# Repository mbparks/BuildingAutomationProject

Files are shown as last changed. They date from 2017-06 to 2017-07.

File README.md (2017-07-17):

# Building Automation Project
brought to you by Mouser Electronics

This repo holds all the information needed to experiment with an IoT-based building automation system that leverages the TE Connectivty Weather Shield.

Current Architecture:
- Arduino 101, 8266 WiFi Shield, TE Connectivity Weather Shield: Sensor package monitors temperature, pressure, and relative humidity. Transmits data to a cloud-based backend.
- Huzzah 8266 monitors data from cloud and makers decision to control ventilation dampers based on presets and current sensor reading.
- Leverage the Ubidots cloud service for the backend.  https://ubidots.com

Bill of Materials (BOM) in a pre-built shopping cart for your convenience:
http://www.mouser.com/ProjectManager/ProjectDetail.aspx?AccessID=098ee3c674

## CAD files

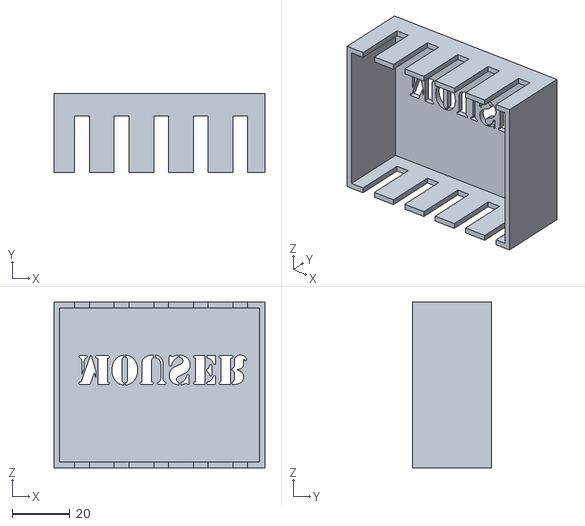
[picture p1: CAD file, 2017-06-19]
Mechanical/Arduino101Components/Arduino101EnclosureTop.stl
73.4 x 27.4 x 57.7

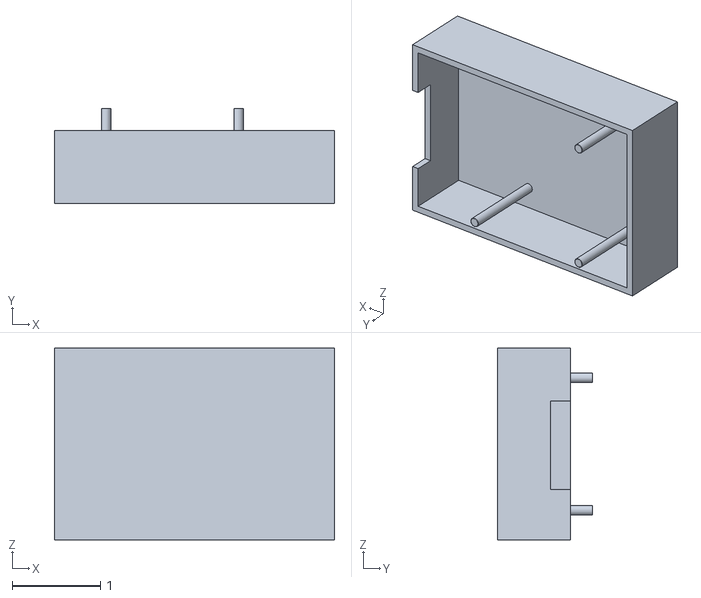
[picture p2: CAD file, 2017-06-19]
Mechanical/HuzzahComponents/HuzzahEnclosureBottom.stl
3.17 x 1.08 x 2.17

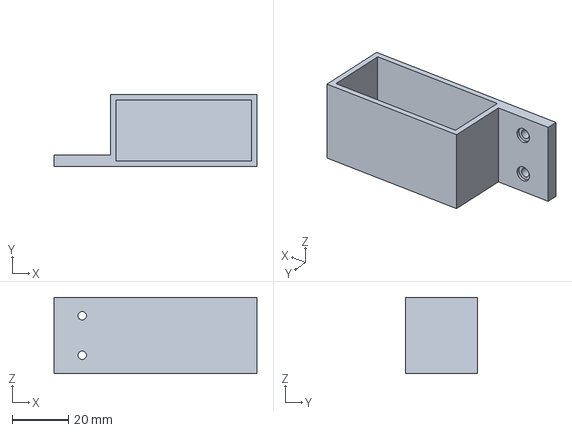
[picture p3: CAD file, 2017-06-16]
Mechanical/ServoMount/ServoHolder (1).amf
72.0 x 25.5 x 27.0 mm

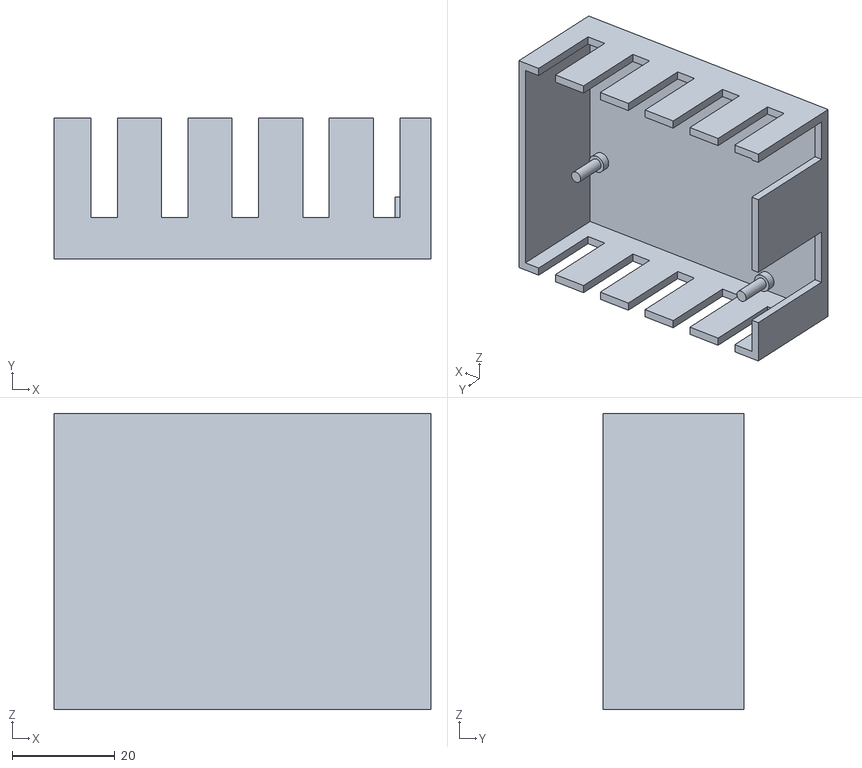
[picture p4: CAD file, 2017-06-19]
Mechanical/Arduino101Components/Arduino101EnclosureBottom.stl
73.4 x 27.4 x 57.7

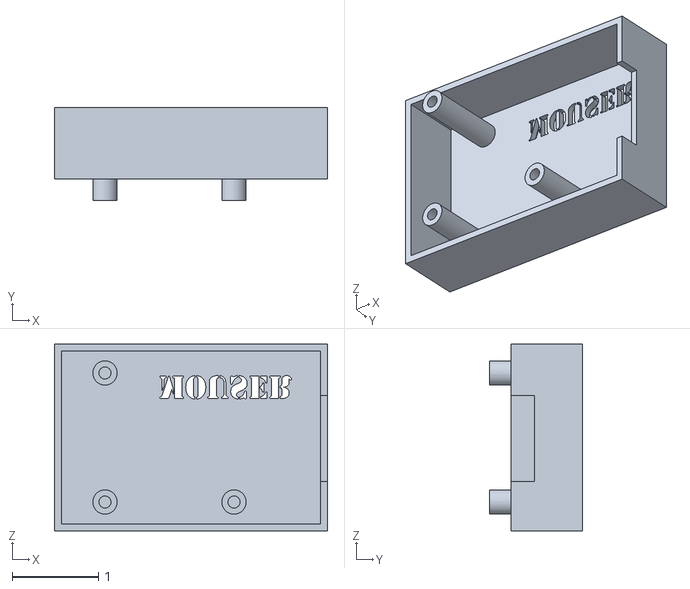
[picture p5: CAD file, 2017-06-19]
Mechanical/HuzzahComponents/HuzzahEnclosureTop.stl
3.17 x 1.08 x 2.17

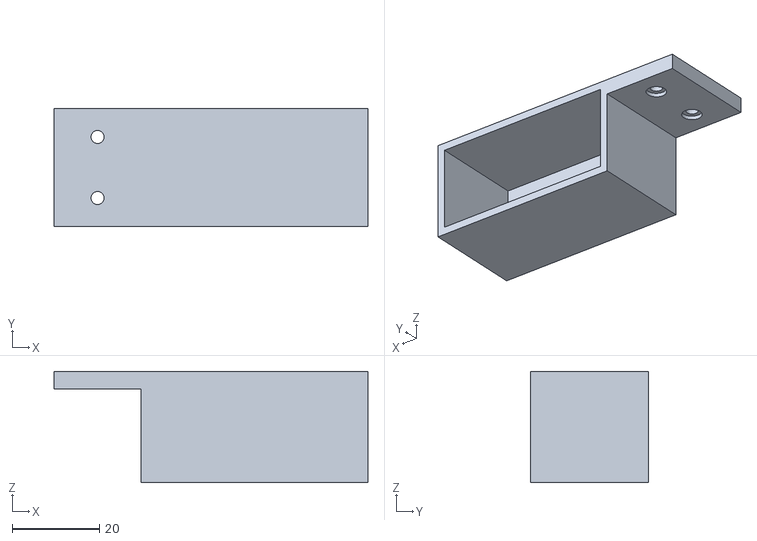
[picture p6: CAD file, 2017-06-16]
Mechanical/ServoMount/ServoHolder.stl
72.0 x 27.0 x 25.5

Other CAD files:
Mechanical/HuzzahComponents/HuzzahEnclosure.f3d
Mechanical/ServoMount/ServoHolder.f3d

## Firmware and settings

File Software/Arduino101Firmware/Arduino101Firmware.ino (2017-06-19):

////////////////////////////////////////
//
////////////////////////////////////////
#include <TEWeatherShield.h>
#include <SoftwareSerial.h> 
#include <SparkFunESP8266WiFi.h>

static TEWeatherShield  weatherShield;

const char mySSID[] = "";
const char myPASS[] = "";

const char ubidotsToken[] = "";
const char humidVarId[] = "";
const char tempVarId[] = "";
const char pressVarId[] = "";
const char destServer[] = "things.ubidots.com";

const int loopDelay = 30000;



/////////////////////////////////////////
//
////////////////////////////////////////
void setup() {
    Serial.begin(9600);
    delay(1000);
    
    // initializeESP8266() verifies communication with the WiFi
    // shield, and sets it up.
    initializeESP8266();

    // connectESP8266() connects to the defined WiFi network.
    connectESP8266();

    // displayConnectInfo prints the Shield's local IP
    // and the network it's connected to.
    displayConnectInfo();
    
    delay(2000);
    weatherShield.begin();
    delay(2000);
    
    Serial.println(F("Mouser Building Automation System Initialized."));
}



/////////////////////////////////////////
//
////////////////////////////////////////
void loop() {
    ESP8266Client client;
    float temperature = -1, pressure = -1, humidity = -1;
    getMeasurements(&temperature, &pressure, &humidity);
    temperature = (temperature * 1.8) + 32;

    int sizeOfPacket = 159;
    sizeOfPacket += getSize(temperature);
    sizeOfPacket += getSize(pressure);
    sizeOfPacket += getSize(humidity);
  

    if(client.connect(destServer, 80)) {
      Serial.println("Connected to Ubidots server, sending payload..");
      
      client.print("POST /api/v1.6/collections/values/?token=");
      client.print(ubidotsToken);
      client.println(" HTTP/1.1");
      client.println("Host: things.ubidots.com");
      client.println("Content-Type: application/json");
      client.print("Content-Length: ");
      client.println(sizeOfPacket);
      client.println();
      client.print("[{\"variable\": \"");
      client.print(tempVarId);
      client.print("\", \"value\":");
      client.print(temperature);
      client.print("}, {\"variable\": \"");
      client.print(humidVarId);
      client.print("\", \"value\":");
      client.print(humidity);
      client.print("}, {\"variable\": \"");
      client.print(pressVarId);
      client.print("\", \"value\":");
      client.print(pressure);
      client.println("}]");

      Serial.print(F("POST /api/v1.6/collections/values/?token="));
      Serial.print(ubidotsToken);
      Serial.println(F(" HTTP/1.1"));
      Serial.println(F("Host: things.ubidots.com"));
      Serial.println(F("Content-Type: application/json"));
      Serial.print(F("Content-Length: "));
      Serial.println(sizeOfPacket);
      Serial.println();
      Serial.print("[{\"variable\": \"");
      Serial.print(tempVarId);
      Serial.print(F("\", \"value\":"));
      Serial.print(temperature);
      Serial.print(F("}, {\"variable\": \""));
      Serial.print(humidVarId);
      Serial.print(F("\", \"value\":"));
      Serial.print(humidity);
      Serial.print(F("}, {\"variable\": \""));
      Serial.print(pressVarId);
      Serial.print(F("\", \"value\":"));
      Serial.print(pressure);
      Serial.println(F("}]"));

      }
      else {
        Serial.println("Cannot conenct ot to Ubidots server!!!");
      }
      
  // available() will return the number of characters
  // currently in the receive buffer.
  while (client.available()) {
    Serial.write(client.read());
  }// read() gets the FIFO char
  
  // connected() is a boolean return value - 1 if the 
  // connection is active, 0 if it's closed.
  if (client.connected()) {
    client.stop(); // stop() closes a TCP connection.
  }

  delay(loopDelay);
}


/////////////////////////////////////////
//
////////////////////////////////////////
void getMeasurements(float *t, float *p, float *h) {
  weatherShield.selectMS8607();

  while(!weatherShield.MS8607.is_connected()) {
    //wait
  }

  if (weatherShield.MS8607.is_connected()) {    
    weatherShield.MS8607.set_humidity_i2c_master_mode(ms8607_i2c_hold); 
    weatherShield.MS8607.read_temperature_pressure_humidity(t, p, h);
    Serial.println();
    Serial.print(F("Temperature : "));
    Serial.print(*t);
    Serial.println(F("C"));

    Serial.print(F("- Pressure : "));
    Serial.print(*p);
    Serial.println(F(" hPa"));
    
    Serial.print(F("- Humidity : "));
    Serial.print(*h);
    Serial.println(F("%RH"));
    Serial.println();
  }

  else {
    Serial.println(F("MS8607 is disconnected"));
  }
}


void initializeESP8266()
{
  // esp8266.begin() verifies that the ESP8266 is operational
  // and sets it up for the rest of the sketch.
  // It returns either true or false -- indicating whether
  // communication was successul or not.
  // true
  int test = esp8266.begin();
  if (test != true)
  {
    Serial.println(F("Error talking to ESP8266."));
    errorLoop(test);
  }
  Serial.println(F("ESP8266 Shield Present"));
}



void connectESP8266()
{
  // The ESP8266 can be set to one of three modes:
  //  1 - ESP8266_MODE_STA - Station only
  //  2 - ESP8266_MODE_AP - Access point only
  //  3 - ESP8266_MODE_STAAP - Station/AP combo
  // Use esp8266.getMode() to check which mode it's in:
  int retVal = esp8266.getMode();
  if (retVal != ESP8266_MODE_STA)
  { // If it's not in station mode.
    // Use esp8266.setMode([mode]) to set it to a specified
    // mode.
    retVal = esp8266.setMode(ESP8266_MODE_STA);
    if (retVal < 0)
    {
      Serial.println(F("Error setting mode."));
      errorLoop(retVal);
    }
  }
  Serial.println(F("Mode set to station"));

  // esp8266.status() indicates the ESP8266's WiFi connect
  // status.
  // A return value of 1 indicates the device is already
  // connected. 0 indicates disconnected. (Negative values
  // equate to communication errors.)
  retVal = esp8266.status();
  if (retVal <= 0)
  {
    Serial.print(F("Connecting to "));
    Serial.println(mySSID);
    // esp8266.connect([ssid], [psk]) connects the ESP8266
    // to a network.
    // On success the connect function returns a value >0
    // On fail, the function will either return:
    //  -1: TIMEOUT - The library has a set 30s timeout
    //  -3: FAIL - Couldn't connect to network.
    retVal = esp8266.connect(mySSID, myPASS);
    if (retVal < 0)
    {
      Serial.println(F("Error connecting"));
      errorLoop(retVal);
    }
  }
}



void displayConnectInfo()
{
  char connectedSSID[24];
  memset(connectedSSID, 0, 24);
  // esp8266.getAP() can be used to check which AP the
  // ESP8266 is connected to. It returns an error code.
  // The connected AP is returned by reference as a parameter.
  int retVal = esp8266.getAP(connectedSSID);
  if (retVal > 0)
  {
    Serial.print(F("Connected to: "));
    Serial.println(connectedSSID);
  }

  // esp8266.localIP returns an IPAddress variable with the
  // ESP8266's current local IP address.
  IPAddress myIP = esp8266.localIP();
  Serial.print(F("My IP: ")); Serial.println(myIP);
}


// errorLoop prints an error code, then loops forever.
void errorLoop(int error)
{
  Serial.print(F("Error: ")); Serial.println(error);
  Serial.println(F("Looping forever."));
  for (;;)
    ;
}



int getSize(int value) {
  int absValue = abs(value);
  int isNegative = 0;
  if (value<0) {
    isNegative = 1;
  }
  if (absValue >= 10000) {
    return 7+isNegative;
  }
  else if (absValue >= 1000) {
    return 6+isNegative;
  }
  else if (absValue >= 100) {
    return 5+isNegative;
  }
  else if (absValue >= 10) {
    return 4+isNegative;
  }
  else {
    return 3+isNegative;
  }
}

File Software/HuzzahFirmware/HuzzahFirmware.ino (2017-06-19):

//////////////////////////////////////////////////////
//
//////////////////////////////////////////////////////
#include <ESP8266WiFi.h>
#include <Servo.h>

static int PWMpin = 2;
static int baffleClosedPosition = 90;
static int baffleOpenPosition = 1;
static int loopDelay = 5000;
static float tempSetpoint = 75.0;

const char mySSID[] = "";
const char myPASS[] = "";
const char ubidotsToken[] = "";
const char ubidotsDeviceLabel[] = "";
const char ubidotsTempVarLabel[] = "temperature";
const char destServer[] = "things.ubidots.com";

const String httpRequest1 = "GET /api/v1.6/devices/Arduino101_MBA/temperature/values?page_size=1&token=";
const String httpRequest2 = " HTTP/1.1\r\n"
                            "Host: things.ubidots.com\r\n"
                            "Connection: close\r\n\r\n";

Servo baffleServo;


//////////////////////////////////////////////////////
//
//////////////////////////////////////////////////////
void setup() {
   
   Serial.begin(115200);
   delay(100);
   
   WiFi.begin(mySSID, myPASS);
   
   Serial.println();
   Serial.println();
   Serial.print("Connecting to ");
   Serial.println(mySSID);
   
   while (WiFi.status() != WL_CONNECTED) {
       delay(500);
       Serial.print(".");
    }

   pinMode(PWMpin, OUTPUT);
   baffleServo.attach(PWMpin);
}




//////////////////////////////////////////////////////
//
//////////////////////////////////////////////////////
void loop() {
    float temperature = 0.0;
    String line = "";

    Serial.print("connecting to ");
    Serial.println(destServer);
    
    WiFiClient client;
    const int httpPort = 80;
    if (!client.connect(destServer, httpPort)) {
        Serial.println("connection failed");
        return;
    }
    
    client.print(httpRequest1+ubidotsToken+httpRequest2);

    delay(500);

    while(client.connected()){
        line.concat(client.readStringUntil('\n'));
    }

    baffleServo.attach(PWMpin);
    //Serial.print(line);
    temperature = cleanHttpResponse(line);
    operateBaffle(temperature);
    delay(loopDelay);
    baffleServo.detach();
}



//////////////////////////////////////////////////////
//
//////////////////////////////////////////////////////
bool operateBaffle(float t) {
    if (t > tempSetpoint) {
        baffleServo.write(baffleOpenPosition);
        Serial.println(F("Baffle is OPEN"));
    }
    else{
        baffleServo.write(baffleClosedPosition);
        Serial.println(F("Baffle is CLOSED"));
    }
}


//////////////////////////////////////////////////////
//
//////////////////////////////////////////////////////
float cleanHttpResponse(String line) {
    line.trim();
    int valueIndexStart = line.indexOf("\"value\":");
    line.remove(0, valueIndexStart+9);
    //Serial.print("FIRST CUT: ");
    //Serial.println(line);
    valueIndexStart = line.indexOf(",");
    line.remove(valueIndexStart);
    //Serial.print("SECOND CUT: ");
    //Serial.println(line);
    float temperature = line.toFloat();
    Serial.print(F("Temperature: "));
    Serial.print(temperature);
    Serial.println("F");
    return temperature;
}

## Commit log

2017-06-08 Huzzah Board init layout
    Initial schematic for a board to hold Huzzah and servo control hardware
    [HuzzahBoard.brd, HuzzahBoard.sch]
2017-06-08 init Arduino 101 Firmware release
2017-06-08 init commit for 3D enclosures
    [Arduino101_Enclosurure v2.f3d, HuzzahEnclosure v2.f3d]
2017-06-08 board updates, move to bottom layer
    [DRILEGEND.CFG, HuzzahBoard.brd]
2017-06-08 first draft of enclosure 3D
    [Arduino101_Enclosurure v2.f3d, HuzzahEnclosure v2.f3d, HuzzahEnclosure.f3d]
2017-06-09 clean up board file
2017-06-10 update Ubidots API for Arduino101
2017-06-16 added 3D model of hardware to mount servo to a sidewall
    [ServoHolder.f3d, ServoHolder.stl]
2017-06-16 revise board layout
    WIre Colors for Servo: ORB - PWM, VCC, GROUND
    [HuzzahBoard.brd]
2017-06-16 servoHolder updates
    [ServoHolder (1).amf]
2017-06-17 corrected the open/close values for the baffle serve
    [HuzzahFirmware.ino]
2017-06-18 Arduino 101/Uno Enclosure revision
    [Arduino101EnclosureBottom.stl, Arduino101EnclosureTop.stl]
2017-06-18 Huzzah enclosure revised
    [HuzzahEnclosureBottom.stl, HuzzahEnclosureTop.stl]
2017-06-19 moved Huzzah mech design to correct folder
    [HuzzahEnclosureBottom.stl, HuzzahEnclosureTop.stl]
